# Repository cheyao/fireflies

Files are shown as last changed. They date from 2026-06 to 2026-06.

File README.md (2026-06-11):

# Fireflies

Firefly PCBs powered by the CH32V003.

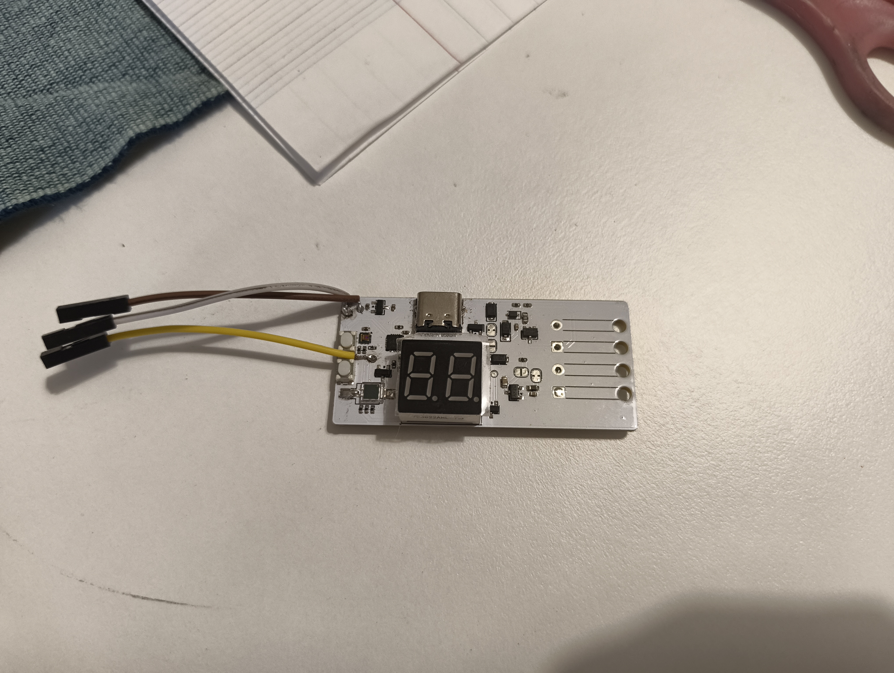
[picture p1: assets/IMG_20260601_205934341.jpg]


These boards periodically flashes a xenon flash based on a timer, which gets accelerated when it detects flashes from surrounding PCBs.

There are currently 2 flash-detection circuits undergoing testing:

1. A reverse-biased diode using the ch32v003's internal OPA & ADC for sampling

2. A I2C ambiant light sensor for more "advanced" applications

The flash trigger isolates the hi-voltage trigger and the low-voltage circuitarry with a triac circuit, and uses a mosfet to trigger the flash.

### Features:

- Dual light-sensor: one via i2c, one via photodiode
- USB via ch32usb
- 7 seg for number display
- Flash activation circuit (high voltage)
- Programming ports

### Usage

Check firmware folder

Here's an example output for detection light intensity with the photodiode:

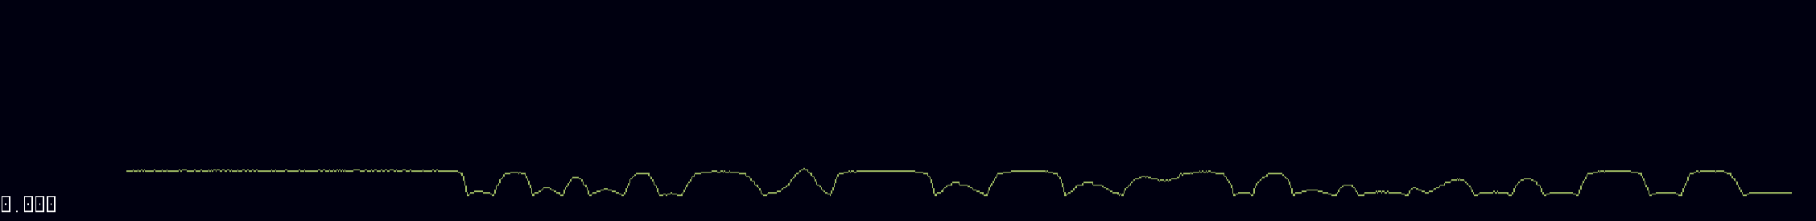
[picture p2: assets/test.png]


It's reverse-biased btw

### Schematic

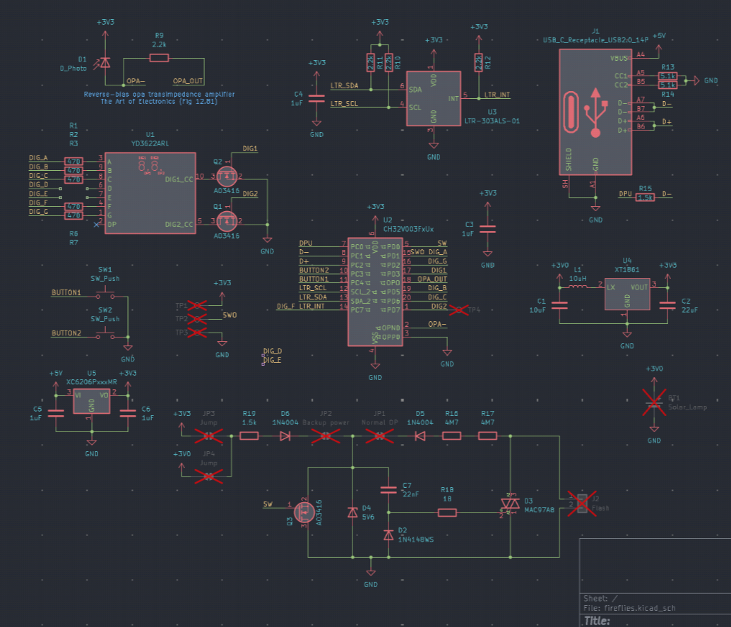
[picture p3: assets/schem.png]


### Programming

Check diagram:

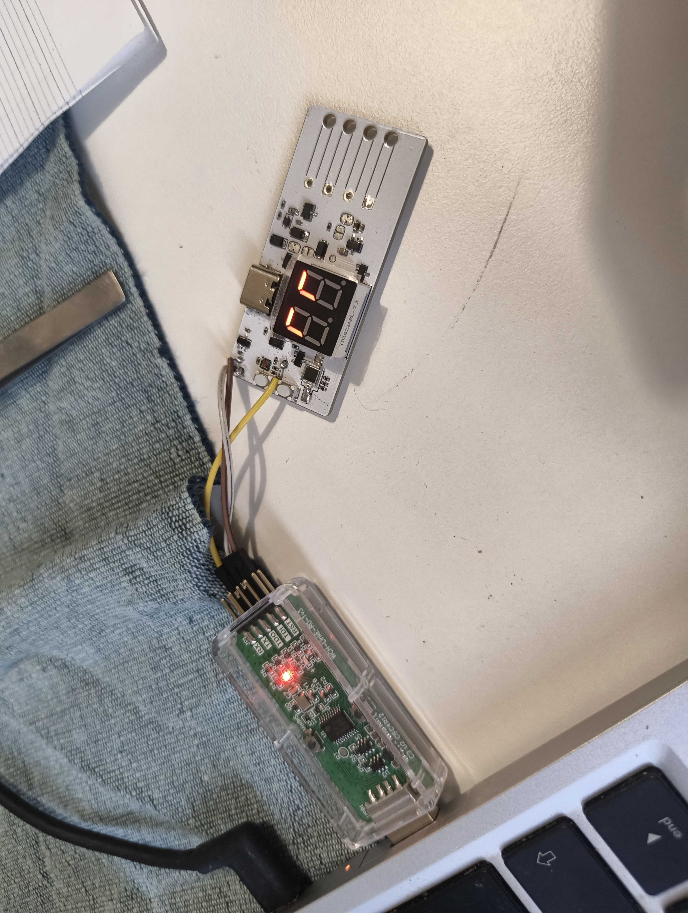
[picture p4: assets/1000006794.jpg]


### BOM

| Item | Price |  Where |
|---|---|----|
|PCB| 4$| elecrow|
|Stencil| 2$| elecrow|
|Components (check hardware bom)| $30| lcsc|
|Shipping| varies by region| none|

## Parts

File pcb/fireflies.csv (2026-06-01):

Reference | Qty | Value | Exclude from BOM | Footprint | LCSC Part #
BT1 | 1 | Solar_Lamp
C1,C3 | 2 | 10uF |  | Capacitor_SMD:C_0402_1005Metric | C15525
C2 | 1 | 22uF |  | Capacitor_SMD:C_0603_1608Metric | C59461
D1 | 1 | D_Photo |  |  | C131196
L1 | 1 | 10uH |  | Inductor_SMD:L_0603_1608Metric | C1035
Q1,Q2 | 2 | AO3416 |  | PCM_Package_TO_SOT_SMD_AKL:SOT-23 | C347499
R1,R2,R3,R4,R5,R6,R7,R8 | 8 | 470 |  | Resistor_SMD:R_0402_1005Metric | C25117
R9 | 1 | TBD
SW1,SW2 | 2 | SW_Push |  |  | C139797
U1 | 1 | YD3622ARL |  | light:YD3622ARL | C46614038
U2 | 1 | CH32V003FxUx |  | Package_DFN_QFN:QFN-20-1EP_3x3mm_P0.4mm_EP1.65x1.65mm | C5299908
U3 | 1 | LTR-303ALS-01 |  | OptoDevice:Lite-On_LTR-303ALS-01 | C492382
U4 | 1 | XT1861 |  | Package_TO_SOT_SMD:SOT-23-3 | C236396

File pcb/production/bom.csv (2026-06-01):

Designator | Footprint | Quantity | Value | LCSC Part #
C1 | 0402 | 1 | 10uF | C15525
C2 | 0603 | 1 | 22uF | C59461
C3, C4, C5, C6 | 0402 | 4 | 1uF | C52923
C7 | 0402 | 1 | 22n | C5137468
D1 | Photodiode_PD70-01C | 1 | D_Photo | C131196
D2 | D_SOD-323 | 1 | 1N4148WS | C2904852
D3 | SOT-23-3 | 1 | MAC97A8 | C2831929
D4 | D_SOD-123 | 1 | 5V6 | C173406
D5, D6 | D_SOD-123F | 2 | 1N4004 | C162734
J1 | USB_C_Receptacle_SHOU_HAN_16PIN_2MD | 1 | USB_C_Receptacle_USB2.0_14P | C2765186
L1 | 0603 | 1 | 10uH | C281107
Q1, Q2, Q3 | SOT-23 | 3 | AO3416 | C347499
R1, R2, R3, R6, R7 | 0402 | 5 | 470 | C25117
R10, R11, R12, R9 | 0402 | 4 | 2.2k | C25879
R13, R14 | 0402 | 2 | 5.1k | C25905
R15, R19 | 0402 | 2 | 1.5k | C25867
R16, R17 | 0402 | 2 | 4M7 | C3013173
R18 | 0603 | 1 | 18 | C2933165
SW1, SW2 | SW_Push_SPST_TSA016 | 2 | SW_Push | C2888430
U1 | YD3622A | 1 | YD3622ARL | C46614038
U2 | QFN-20-1EP_3x3mm_P0.4mm_EP1.65x1.65mm_ThermalVias | 1 | CH32V003FxUx | C5299908
U3 | Lite-On_LTR-303ALS-01 | 1 | LTR-303ALS-01 | C492382
U4 | SOT-23-3 | 1 | XT1861 | C236396
U5 | SOT-23-3 | 1 | XC6206PxxxMR | C347376

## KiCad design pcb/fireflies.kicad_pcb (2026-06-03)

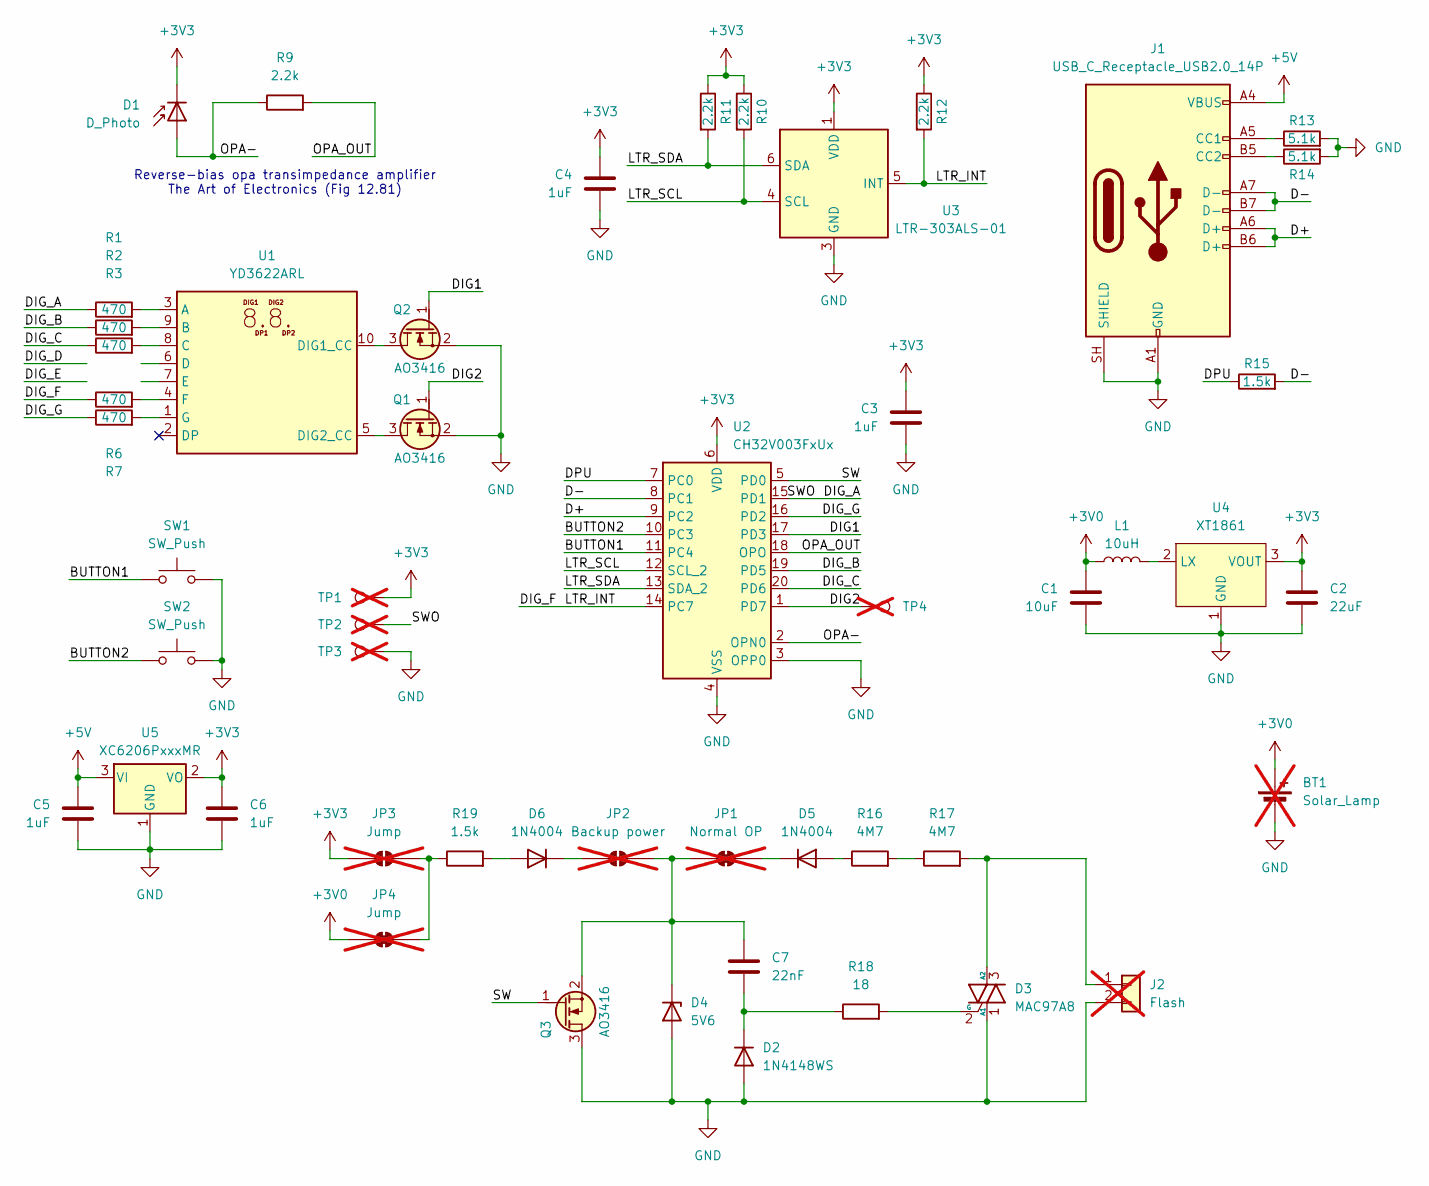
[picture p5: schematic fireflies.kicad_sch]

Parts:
BT1: Solar_Lamp; SolderWire-0.5sqmm_1x02_P4.6mm_D0.9mm_OD2.1mm_Relief; not fitted
C1: 10uF; C_0402_1005Metric; LCSC Part # C15525
C2: 22uF; C_0603_1608Metric; LCSC Part # C59461
C3, C4, C5, C6: 1uF; C_0402_1005Metric; LCSC Part # C52923
C7: 22nF; C_0402_1005Metric; LCSC Part # C5137627
D1: D_Photo; Photodiode_PD70-01C; LCSC Part # C131196
D2: 1N4148WS; D_SOD-323; LCSC Part # C2904852
D3: MAC97A8; SOT-23-3; LCSC Part # C2831929
D4: 5V6; D_SOD-123; LCSC Part # C173406
D5, D6: 1N4004; D_SOD-123F; LCSC Part # C162734
J1: USB_C_Receptacle_USB2.0_14P; USB_C_Receptacle_SHOU_HAN_16PIN_2MD; LCSC Part # C2765186
J2: Flash; SolderWire-0.5sqmm_1x02_P4.6mm_D0.9mm_OD2.1mm_Relief; not fitted
JP1: Normal OP; SolderJumper-2_P1.3mm_Bridged_RoundedPad1.0x1.5mm; not fitted
JP2: Backup power; SolderJumper-2_P1.3mm_Open_RoundedPad1.0x1.5mm; not fitted
JP3: Jump; SolderJumper-2_P1.3mm_Open_RoundedPad1.0x1.5mm; not fitted
JP4: Jump; SolderJumper-2_P1.3mm_Bridged_RoundedPad1.0x1.5mm; not fitted
L1: 10uH; L_0603_1608Metric; LCSC Part # C281107
Q1, Q2, Q3: AO3416; SOT-23; LCSC Part # C347499
R1, R2, R3, R6, R7: 470; R_0402_1005Metric; LCSC Part # C25117
R9, R10, R11, R12: 2.2k; R_0402_1005Metric; LCSC Part # C25879
R13, R14: 5.1k; R_0402_1005Metric; LCSC Part # C25905
R15, R19: 1.5k; R_0402_1005Metric; LCSC Part # C25867
R16, R17: 4M7; R_0402_1005Metric; LCSC Part # C3013173
R18: 18; R_0603_1608Metric; LCSC Part # C2933165
SW1, SW2: SW_Push; SW_Push_SPST_TSA016; LCSC Part # C2888430
TP1, TP2, TP3, TP4: TestPoint; TestPoint_Pad_D1.0mm; not fitted
U1: YD3622ARL; YD3622A; LCSC Part # C46614038
U2: CH32V003FxUx; QFN-20-1EP_3x3mm_P0.4mm_EP1.65x1.65mm_ThermalVias; LCSC Part # C5299908
U3: LTR-303ALS-01; Lite-On_LTR-303ALS-01; LCSC Part # C492382
U4: XT1861; SOT-23-3; LCSC Part # C236396
U5: XC6206PxxxMR; SOT-23-3; LCSC Part # C347376

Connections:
+3V0: BT1.1 (+), C1.1, JP4.1 (A), L1.1
+3V3: C2.1, C3.1, C4.1, C6.1, D1.1 (K), JP3.1 (A), R10.1, R11.1, R12.1, TP1.1 (1_1), U2.6 (VDD), U3.1 (VDD), U4.3 (VOUT), U5.2 (VO)
+5V: C5.1, J1.A4 (VBUS), J1.A9 (VBUS), J1.B4 (VBUS), J1.B9 (VBUS), U5.3 (VI)
/BUTTON1: SW1.1, U2.11 (PC4)
/BUTTON2: SW2.1, U2.10 (PC3)
/D+: J1.A6 (D+), J1.B6 (D+), U2.9 (PC2)
/D-: J1.A7 (D-), J1.B7 (D-), R15.2, U2.8 (PC1)
/DIG1: Q2.1 (G), U2.17 (PD3)
/DIG2: Q1.1 (G), TP4.1 (1_1), U2.1 (PD7)
/DIG_A: R1.1, TP2.1 (1_1), U2.15 (PD1)
/DIG_B: R2.1, U2.19 (PD5)
/DIG_C: R3.1, U2.20 (PD6)
/DIG_F: R6.1, R12.2, U2.14 (PC7), U3.5 (INT)
/DIG_G: R7.1, U2.16 (PD2)
/DPU: R15.1, U2.7 (PC0)
/LTR_SCL: R10.2, U2.12 (SCL_2), U3.4 (SCL)
/LTR_SDA: R11.2, U2.13 (SDA_2), U3.6 (SDA)
/OPA-: D1.2 (A), R9.1, U2.2 (OPN0)
/OPA_OUT: R9.2, U2.18 (OPO)
/SW: Q3.1 (G), U2.5 (PD0)
GND: BT1.2 (-), C1.2, C2.2, C3.2, C4.2, C5.2, C6.2, D2.2 (A), D3.1 (A1), D4.2 (A), J1.A1 (GND), J1.A12 (GND), J1.B1 (GND), J1.B12 (GND), J1.SH (SHIELD), J2.2, Q1.2 (S), Q2.2 (S), Q3.3 (D), R13.2, R14.2, SW1.2, SW2.2, TP3.1 (1_1), U2.3 (OPP0), U2.4 (VSS), U2.21 (VSS), U3.3 (GND), U4.1 (GND), U5.1 (GND)
unnamed: C7.2, D2.1 (K), R18.1
unnamed: D3.3 (A2), J2.1, R17.2
unnamed: D3.2 (G), R18.2
unnamed: C7.1, D4.1 (K), JP1.1 (A), JP2.2 (B), Q3.2 (S)
unnamed: D5.2 (A), R16.1
unnamed: D5.1 (K), JP1.2 (B)
unnamed: D6.2 (A), R19.2
unnamed: D6.1 (K), JP2.1 (A)
unnamed: J1.A5 (CC1), R13.1
unnamed: J1.B5 (CC2), R14.1
unnamed: JP3.2 (B), JP4.2 (B), R19.1
unnamed: Q1.3 (D), U1.5 (DIG2_CC)
unnamed: Q2.3 (D), U1.10 (DIG1_CC)
unnamed: R16.2, R17.1
unnamed: R1.2, U1.3 (A)
unnamed: R2.2, U1.9 (B)
unnamed: R3.2, U1.8 (C)
unnamed: R6.2, U1.4 (F)
unnamed: R7.2, U1.1 (G)
unnamed: L1.2, U4.2 (LX)

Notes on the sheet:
Reverse-bias opa transimpedance amplifier The Art of Electronics (Fig 12.81)

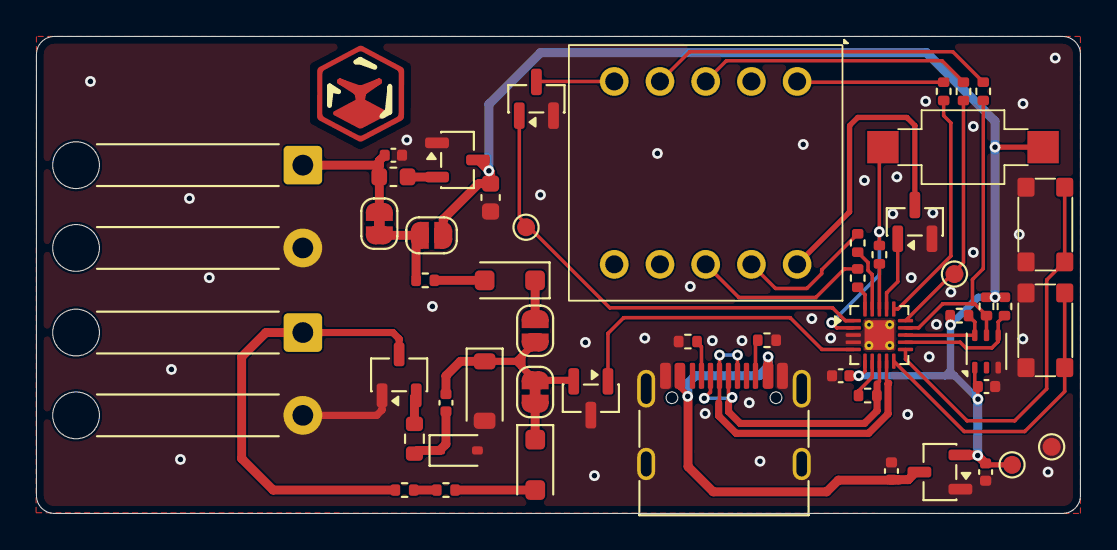
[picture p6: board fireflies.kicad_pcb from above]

Board: 2 copper layers, 58.0 x 26.5 mm, 51 parts (0 on the bottom side), 41 nets.

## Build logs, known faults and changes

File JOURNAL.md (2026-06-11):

# 2026-06-11: Transfered project!

**Total time spent: 1.7 hours**



Transfered project from macando to forge, it was an enourmous pita to copy and paste all the journals and format everything



Also added a demo of reverse biases opamp attenuated light sensing!

# 2026-06-11: Got software I2C to work

**Total time spent: 4.2 hours**



implemented custom software I2C to use the amient light sensor - it became a lot more accurate

You can see the dips n stuff clearly - it works! It can detect flashes

# 2026-06-11: Flash test! 

**Total time spent: 3.8 hours**

Today I dissasembled a flash to test the light sensing.

Fumbled with bare-metal and ch32fun to write software I2C for sensing chip.



Got this at first



Then I disassembled this flash

Reverse engineered its circuits, got it to flash and got a new graph!

Software I2C was a huge pita



# 2026-06-11: Wrote the firmware! 

**Total time spent: 6.3 hours**



After getting my programmer, I finally can write my firmware. 



The stuff was in bare metal, so a tiny tad hard







Had to read through pages of memaps and stuff - this isn't like arduinos and rpis where everything is abstract and have sdks, there isn't even any libs available 



But I got this nice brightness graph from the photodiode!

# 2026-06-11: Finally I gave up and ordered an linke 

**Total time spent: 2.3 hours**

After some more research, I gave up and ordered a linke ... very big sob and very sad I know........



Discussed it a bit more with people on discord to try to figure everything out, to no avail



# 2026-06-11: Then I even tried to code my ownprogrammer 

**Total time spent: 6.4 hours**



I even tried to program my own programmer with tinyusb and a pico.

Learnt about USB with https://beyondlogic.org/usbnutshell/usb1.shtml



found this site



And even wrote my own USB descriptors and stuff



Endpoints are 1:1 imitiations to real linke, but then I couldn't reverse-engineer protocol due to not having a linke



It became aval to enum, but there was no public protocol documentation...

Code is on github repo

# 2026-06-11: Try to alt programmers 

**Total time spent: 4.3 hours**

Then I tried to use alt programmers.

Like https://gitlab.com/BlueSyncLine/arduino-ch32v003-swio and https://github.com/aappleby/picorvd, but both didn't work...






Even made my own edits in picorvd to try and debug stuff, to no avail. GDB was always returning 0

# 2026-06-11: Soldered side-project to debug 

**Total time spent: 4.7 hours**



Then I soldered one of these comus - also hand pnp and solder reflow, but all 0201s. It was hell and printed a plate too!

It was only 1cmx2cm so pretty hard to solder



In the same time I also soldered wires on a old USB A project to try to program it easily, and yep, it didn't work!

# 2026-06-11: Broke programmer and soldered 3 more boards 

**Total time spent: 7.2 hours**

Welp guess what, I broke my programmer

Tried to debug why my programmer was returning 0000000000s

Was damn weird...... And to debug it, I unsoldered ~2 known-good boards from past projects, and assembled more boards:



Spent a ton of time soldering 3 more PCBs. Hand assemble, hand solder.



Used stencil to apply paste

# 2026-06-11: Soldered the PCB!

**Total time spent: 4.7 hours**



Good thing I had the interactive BOM to use with me



So soldered everything and tried proging it!

Did the reflow on a hotplate



Played with it a tiny bit...

# 2026-06-11: Finished BOM

**Total time spent: 2.2 hours**



Finished the BOM! Bom optimized this to use the least components.

Pretty proud of the job I did for this

Finished the BOM! Bom optimized the use the least components.

Pretty proud of the job I did for this



Got the grant!

# 2026-06-11: Finished PCB 

**Total time spent: 8.9 hours**



Added a light sensor - chose one that satisfied reqs and was cheap



Finished the PCB - re-routed it a few times to ensure the lowest size and smallest form factor.



Used these types of holes to remove mechanical stress from solder joints




Also got a quote for the PCB and stencil



Also made custom footpritns





A custom symbol for the v006 was also made but not used

# 2026-06-11: Research, discussions and end schematic 

**Total time spent: 7.9 hours**



Had a big very fancy and lengthy discussion with people on a discord server about the project! Also discussed scope even more



Also did a ton of research on old xenon flashes, including pulling up designs from repair shops and forums





Also looked into alternative light recieving sources, and added a 2nd impl.

Made all this circuit in the time too


Mainly implemented high-voltage switching that can be controled by 3.3v mcu



The 7seg also got multiplexed

# 2026-06-11: Version 1 of the schematic 

**Total time spent: 6.5 hours**



Bom optimized the hell out of this and sqeezed as much money out of it



And asked a ton of follow-up questions about the project



Read a bit of AoE to get the designs right



Using built-in opa as amplifier circuit

# 2026-06-11: Learnign about project requirements 

**Total time spent: 3.9 hours**






Had big discussions w/ HQ member about the requirements and scope of the project, refer to the images



Did research on what was needed etc

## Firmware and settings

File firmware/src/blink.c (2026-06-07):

#include "ch32fun.h"

#include <stdio.h>

// I2C2 (PC)
#define PIN_SDA PC6
#define PIN_SCL PC5
#define ADDR_READ

#define DELAY1 Delay_Us(1);
#define DELAY2 Delay_Us(2);
#define DSCL_IHIGH                                                                                                     \
	{                                                                                                              \
		funPinMode(PIN_SCL, GPIO_CFGLR_IN_PUPD);                                                               \
		funDigitalWrite(PIN_SCL, 1);                                                                           \
	}
#define DSDA_IHIGH                                                                                                     \
	{                                                                                                              \
		funPinMode(PIN_SDA, GPIO_CFGLR_IN_PUPD);                                                               \
		funDigitalWrite(PIN_SDA, 1);                                                                           \
	}
#define DSDA_INPUT                                                                                                     \
	{                                                                                                              \
		funPinMode(PIN_SDA, GPIO_CFGLR_IN_PUPD);                                                               \
		funDigitalWrite(PIN_SDA, 1);                                                                           \
	}
#define DSCL_OUTPUT                                                                                                    \
	{                                                                                                              \
		funDigitalWrite(PIN_SCL, 0);                                                                           \
		funPinMode(PIN_SCL, GPIO_CFGLR_OUT_2Mhz_PP);                                                           \
	}
#define DSDA_OUTPUT                                                                                                    \
	{                                                                                                              \
		funDigitalWrite(PIN_SDA, 0);                                                                           \
		funPinMode(PIN_SDA, GPIO_CFGLR_OUT_2Mhz_PP);                                                           \
	}
#define READ_DSDA funDigitalRead(PIN_SDA)
#define I2CNEEDGETBYTE 1
#define I2CNEEDSCAN 0

#include "static_i2c.h"

volatile uint16_t adc_buffer[1];

void setup_opa(void);

#define SENSOR_WRITE 0xA6
#define SENSOR_READ 0xA7

#define MAIN_CTRL 0x00
#define ALS_MEAS_RATE 0x04
#define ALS_GAIN 0x05
#define PART_ID 0x06
#define MAIN_STATUS 0x07
#define ALS_DATA_0 0x0D
#define ALS_DATA_1 0x0E
#define ALS_DATA_2 0x0F
#define INT_CFG 0x19
#define INT_PST 0x1A
#define ALS_THRES_UP_0 0x21
#define ALS_THRES_UP_1 0x22
#define ALS_THRES_UP_2 0x23
#define ALS_THRES_LOW_0 0x24
#define ALS_THRES_LOW_1 0x25
#define ALS_THRES_LOW_2 0x26

static uint8_t ReadByte(const uint8_t reg) {
	SendStart();
	SendByte(SENSOR_WRITE);
	SendByte(reg);
	SendStart();
	SendByte(SENSOR_READ);
	const uint8_t data = GetByte(1);
	SendStop();

	return data;
}

int main() {
	SystemInit();
	funGpioInitAll();

	ConfigI2C();

	// Example: 0xA6: 10100110
	// ...SD...............E.R
	// ---____--___--___--__--_
	// --___-----_____----x-zz-

	// Set resolution to 25ms
	SendStart();
	SendByte(SENSOR_WRITE);
	SendByte(ALS_MEAS_RATE);
	SendByte(0b01000000);
	SendStop();
    
    // Gain
	SendStart();
	SendByte(SENSOR_WRITE);
	SendByte(ALS_GAIN);
	SendByte(0b00000100);
	SendStop();

	// Enable
	SendStart();
	SendByte(SENSOR_WRITE);
	SendByte(MAIN_CTRL);
	SendByte(0b00000010);
	SendStop();

	// Read status
	while (1) {
		const uint8_t status = ReadByte(MAIN_STATUS);

		Delay_Ms(1);

		if (!(status & (1 << 3))) {
			// No new data
			continue;
		}

		const uint32_t value =
			(ReadByte(ALS_DATA_2) << 16) | (ReadByte(ALS_DATA_1) << 8) | (ReadByte(ALS_DATA_0) << 0);
		printf("0x%lx\n", value);
	}
}

void setup_opa(void) {
	RCC->CFGR0 &= ~(0x1F << 11);
	RCC->APB2PCENR |= RCC_APB2Periph_ADC1;

	// PD4 is analog input chl 7
	GPIOD->CFGLR &= ~(0xF << (4 * 4));

	// Reset the ADC to init all regs
	RCC->APB2PRSTR |= RCC_APB2Periph_ADC1;
	RCC->APB2PRSTR &= ~RCC_APB2Periph_ADC1;

	// Set up four conversions on chl 7, 4, 3, 2
	ADC1->RSQR1 = 0 << 20; // four chls in the sequence
	ADC1->RSQR2 = 0;
	ADC1->RSQR3 = 7 << (5 * 0);

	// set sampling time for chl 7, 4, 3, 2
	// 0:7 => 3/9/15/30/43/57/73/241 cycles
	ADC1->SAMPTR2 = 7 << (3 * 7);

	// turn on ADC
	ADC1->CTLR2 |= ADC_ADON;

	// Reset calibration
	ADC1->CTLR2 |= ADC_RSTCAL;
	while (ADC1->CTLR2 & ADC_RSTCAL)
		;

	// Calibrate
	ADC1->CTLR2 |= ADC_CAL;
	while (ADC1->CTLR2 & ADC_CAL)
		;

	// Turn on DMA
	RCC->AHBPCENR |= RCC_AHBPeriph_DMA1;

	// DMA1_Channel1 is for ADC
	DMA1_Channel1->PADDR = (uint32_t)&ADC1->RDATAR;
	DMA1_Channel1->MADDR = (uint32_t)adc_buffer;
	DMA1_Channel1->CNTR = 1;
	DMA1_Channel1->CFGR = DMA_M2M_Disable | DMA_Priority_VeryHigh | DMA_MemoryDataSize_HalfWord |
			      DMA_PeripheralDataSize_HalfWord | DMA_MemoryInc_Enable | DMA_Mode_Circular |
			      DMA_DIR_PeripheralSRC;

	// Turn on DMA channel 1
	DMA1_Channel1->CFGR |= DMA_CFGR1_EN;

	// enable scanning
	ADC1->CTLR1 |= ADC_SCAN;

	// Enable continuous conversion and DMA
	ADC1->CTLR2 |= ADC_CONT | ADC_DMA | ADC_EXTSEL;

	// start conversion
	ADC1->CTLR2 |= ADC_SWSTART;

	// turn on the op-amp
	EXTEN->EXTEN_CTR |= EXTEN_OPA_EN;

	EXTEN->EXTEN_CTR &= ~EXTEN_OPA_PSEL;
	EXTEN->EXTEN_CTR &= ~EXTEN_OPA_NSEL;
}

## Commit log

2026-06-01 Opps didn't push hardware
    [bom.csv, designators.csv, fireflies.csv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]
2026-06-03 Hardware i2c stub
    [fireflies.kicad_pcb, fireflies.kicad_sch]
2026-06-07 Sensor I2C
